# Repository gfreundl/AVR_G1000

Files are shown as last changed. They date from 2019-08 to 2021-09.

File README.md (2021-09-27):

G1000 HID unit 

This is a hardware simulator for the G1000, the most popular glass cockpit system in the GA fleet.  

The 3D model is based on the original device, has accurate dimensions and is available in STP format.  

Schematics and PCB layout are in the Eagle folder.  
All inputs are read by three ATMega16 MCU with USB firmware, linked together on a FE1.1s USB Hub chip.
No BOM is provided, as most parts are generic. The encoders are Alps STEC (volume) and ELMA E33 / E37 (all others)
The joystick is an Alps RKJXT1F42001, which is soldered on the copper side.

Sourcecode is mainly based on the V-USB driver firmware from obdev/v-usb

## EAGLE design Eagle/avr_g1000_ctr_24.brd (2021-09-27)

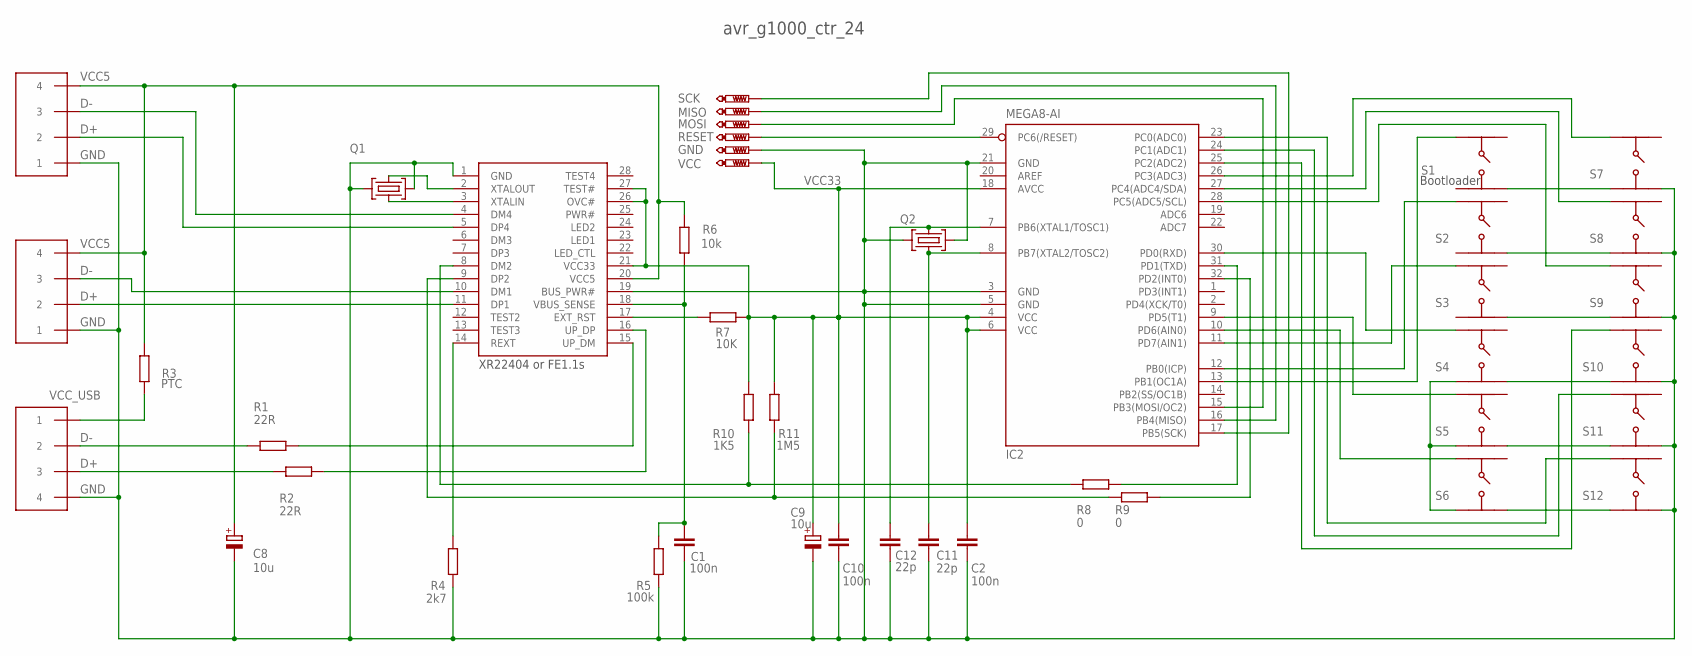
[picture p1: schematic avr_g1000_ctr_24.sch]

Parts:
C1, C2, C10: 100n; C0402
C8, C9: 10u; SMC_A
C11, C12: 22p; C0402
GND: PTR1TP10R; TP10R
IC2: MEGA8-AI; TQFP32-08
MISO: PTR1TP10R; TP10R
MOSI: PTR1TP10R; TP10R
Q1: 12MHz; OSCCC500X320X100
Q2: 12Mhz; OSCCC500X320X100
R1, R2: 22R; R0603
R3: PTC; R0805
R4: 2k7; R0603
R5: 100k; R0603
R6: 10k; R0603
R7: 10K; R0603
R8, R9: 0; R0603
R10: 1K5; R0603
R11: 1M5; R0603
RESET: PTR1TP10R; TP10R
S1, S2, S3, S4, S5, S6, S7, S8, S9, S10, S11, S12: B3FS1000
SCK: PTR1TP10R; TP10R
U$1, U$2, U$3: HEADER4X1.27
VCC: PTR1TP10R; TP10R
XR22404: XR22404

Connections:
D+: R2.1, U$1.P3 (3)
D-: R1.1, U$1.P2 (2)
DM1: U$2.P3 (3), XR22404.10 (DM1)
DM2: R8.1, R10.1, XR22404.8 (DM2)
DM4: U$3.P3 (3), XR22404.4 (DM4)
DP1: U$2.P2 (2), XR22404.11 (DP1)
DP2: R9.1, R11.1, XR22404.9 (DP2)
DP4: U$3.P2 (2), XR22404.5 (DP4)
EXT_RST: R7.1, XR22404.17 (EXT_RST)
GND: C1.2, C2.2, C8.-, C9.-, C10.2, C11.2, C12.2, GND.TP, IC2.3 (GND), IC2.5 (GND), IC2.21 (GND), Q1.2 (GND1), Q1.4 (GND2), Q2.2 (GND1), Q2.4 (GND2), R4.1, R5.1, S1.1, S2.1, S3.1, S4.1, S4.2, S5.1, S5.2, S6.1, S6.2, S7.1, S7.2, S8.1, S8.2, S9.1, S9.2, S10.1, S10.2, S11.1, S11.2, S12.1, S12.2, U$1.P4 (4), U$2.P1 (1), U$3.P1 (1), XR22404.1 (GND), XR22404.19 (BUS_PWR#)
MISO: IC2.16 (PB4(MISO)), MISO.TP
MOSI: IC2.15 (PB3(MOSI/OC2)), MOSI.TP
PB0: IC2.12 (PB0(ICP)), S2.4
PB1: IC2.13 (PB1(OC1A)), S1.4
PC0: IC2.23 (PC0(ADC0)), S12.4
PC1: IC2.24 (PC1(ADC1)), S11.4
PC2: IC2.25 (PC2(ADC2)), S10.4
PC3: IC2.26 (PC3(ADC3)), S7.4
PC4: IC2.27 (PC4(ADC4/SDA)), S8.4
PC5: IC2.28 (PC5(ADC5/SCL)), S9.4
PD0: IC2.30 (PD0(RXD)), S4.4
PD1: IC2.31 (PD1(TXD)), R8.2
PD2: IC2.32 (PD2(INT0)), R9.2
PD5: IC2.9 (PD5(T1)), S5.4
PD6: IC2.10 (PD6(AIN0)), S6.4
PD7: IC2.11 (PD7(AIN1)), S3.4
RESET: IC2.29 (PC6(/RESET)), RESET.TP
REXT: R4.2, XR22404.14 (REXT)
SCK: IC2.17 (PB5(SCK)), SCK.TP
UP_DM: R1.2, XR22404.15 (UP_DM)
UP_DP: R2.2, XR22404.16 (UP_DP)
VBUS_SENSE: C1.1, R5.2, R6.1, XR22404.18 (VBUS_SENSE)
VCC5: C8.+, R3.2, R6.2, U$2.P4 (4), U$3.P4 (4), XR22404.20 (VCC5)
VCC33: C2.1, C9.+, C10.1, IC2.4 (VCC), IC2.6 (VCC), IC2.18 (AVCC), R7.2, R10.2, R11.2, VCC.TP, XR22404.21 (VCC33), XR22404.26 (OVC#), XR22404.27 (TEST#)
VCC_USB: R3.1, U$1.P1 (1)
XTAL1: C12.1, IC2.7 (PB6(XTAL1/TOSC1)), Q2.1 (CRYSTAL1)
XTAL2: C11.1, IC2.8 (PB7(XTAL2/TOSC2)), Q2.3 (CRYSTAL2)
XTALIN: Q1.3 (CRYSTAL2), XR22404.3 (XTALIN)
XTALOUT: Q1.1 (CRYSTAL1), XR22404.2 (XTALOUT)

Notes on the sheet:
avr_g1000_ctr_24
XR22404 or FE1.1s
Bootloader

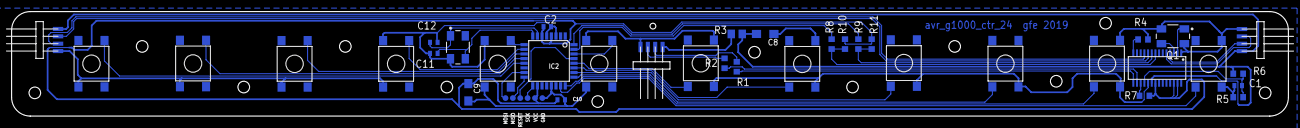
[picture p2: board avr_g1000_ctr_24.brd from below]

Board: 2 copper layers, 220.0 x 18.0 mm, 43 parts (43 on the bottom side), 39 nets.

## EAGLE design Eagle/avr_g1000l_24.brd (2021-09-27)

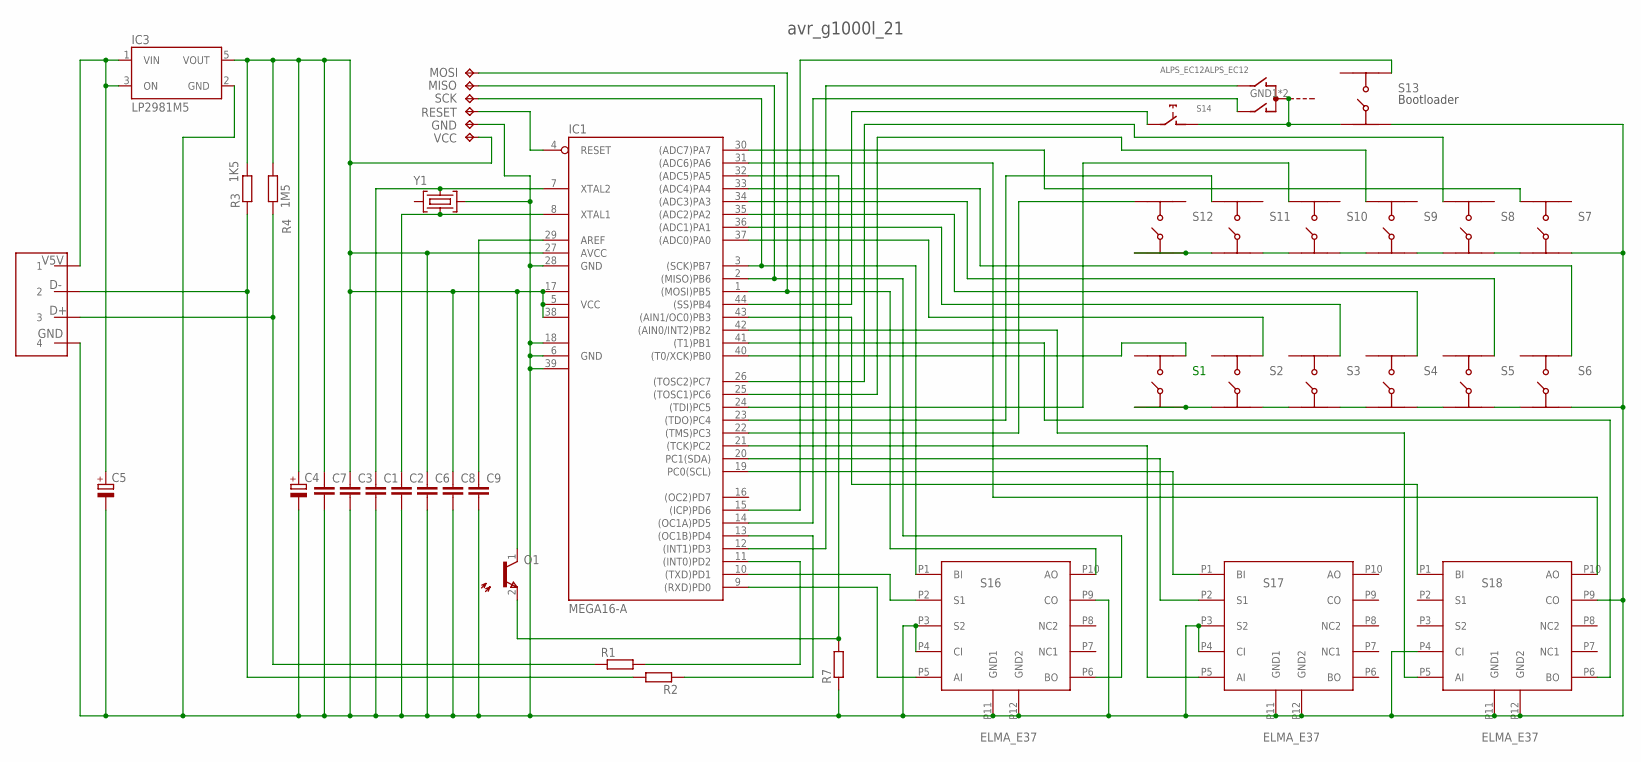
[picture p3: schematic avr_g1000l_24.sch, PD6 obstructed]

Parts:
C1, C2, C3, C6, C7, C8, C9: C-EUC0402; C0402
C4, C5: CPOL-EUSMCA; SMC_A
GND: TPTP10R; TP10R
IC1: MEGA16-A; TQFP44
IC3: LP2981M5; SOT23-5
MISO: TPTP10R; TP10R
MOSI: TPTP10R; TP10R
O1: KPS-3227KPS-3227; RESC3216X110
R1, R2, R7: R-EU_R0603; R0603
R3: 1K5; R0603
R4: 1M5; R0603
RESET: TPTP10R; TP10R
S1, S2, S3, S4, S5, S6, S7, S8, S9, S10, S11, S12, S13: B3FS1000
S14: ALPS_EC12ALPS_EC12; ALPS_EC12E_SW
S16, S17, S18: ELMA_E37
SCK: TPTP10R; TP10R
U$4: HEADER4X1.27
VCC: TPTP10R; TP10R
Y1: MJ-CRYSTALMJ; OSCCC500X320X100

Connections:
D+: R2.2, R3.1, U$4.P2 (2)
D-: R1.1, R4.1, U$4.P3 (3)
GND: C1.2, C2.2, C3.2, C4.-, C5.-, C6.2, C7.2, C8.2, C9.2, GND.TP, IC1.6 (GND), IC1.18 (GND1), IC1.28 (GND), IC1.39 (GND2), IC3.2 (GND), R7.1, S1.3, S1.4, S2.3, S2.4, S3.3, S3.4, S4.3, S4.4, S5.3, S5.4, S6.3, S6.4, S7.3, S7.4, S8.3, S8.4, S9.3, S9.4, S10.3, S10.4, S11.3, S11.4, S12.3, S12.4, S13.3, S13.4, S14.C, S14.D (1), S14.GND1 (G), S14.GND2 (G), S16.P3 (S2), S16.P4 (CI), S16.P9 (CO), S16.P11 (GND1), S16.P12 (GND2), S17.P3 (S2), S17.P4 (CI), S17.P11 (GND1), S17.P12 (GND2), S18.P4 (CI), S18.P9 (CO), S18.P11 (GND1), S18.P12 (GND2), U$4.P4 (4), Y1.2 (GND1)
PA0: IC1.37 ((ADC0)PA0), S2.2
PA1: IC1.36 ((ADC1)PA1), S3.2
PA2: IC1.35 ((ADC2)PA2), S4.2
PA3: IC1.34 ((ADC3)PA3), S5.2
PA4: IC1.33 ((ADC4)PA4), S6.2
PA5: IC1.32 ((ADC5)PA5), O1.2 (E), R7.2
PA6: IC1.31 ((ADC6)PA6), S18.P10 (AO)
PA7: IC1.30 ((ADC7)PA7), S7.1
PB0: IC1.40 ((T0/XCK)PB0), S1.2
PB1: IC1.41 ((T1)PB1), S18.P6 (BO)
PB2: IC1.42 ((AIN0/INT2)PB2), S18.P5 (AI)
PB3: IC1.43 ((AIN1/OC0)PB3), S18.P1 (BI)
PB4: IC1.44 ((SS)PB4), S14.E (2)
PB5: IC1.3 ((SCK)PB7), S16.P1 (BI), SCK.TP
PB6: IC1.1 ((MOSI)PB5), MOSI.TP, S16.P10 (AO)
PB7: IC1.2 ((MISO)PB6), MISO.TP, S16.P6 (BO)
PC0: IC1.19 (PC0(SCL)), S17.P1 (BI)
PC1: IC1.20 (PC1(SDA)), S17.P2 (S1)
PC2: IC1.21 ((TCK)PC2), S17.P5 (AI)
PC3: IC1.22 ((TMS)PC3), S12.1
PC4: IC1.23 ((TDO)PC4), S11.1
PC5: IC1.24 ((TDI)PC5), S10.1
PC6: IC1.25 ((TOSC1)PC6), S9.1
PC7: IC1.26 ((TOSC2)PC7), S8.1
PD0: IC1.9 ((RXD)PD0), S16.P5 (AI)
PD1: IC1.10 ((TXD)PD1), S16.P2 (S1)
PD2: IC1.13 ((OC1B)PD4), R2.1
PD3: IC1.12 ((INT1)PD3), S14.B
PD4: IC1.11 ((INT0)PD2), R1.2
PD5: IC1.14 ((OC1A)PD5), S14.A
PD6: IC1.15 ((ICP)PD6), S13.2
RESET: IC1.4 (RESET), RESET.TP
V5V: C5.+, IC3.1 (VIN), IC3.3 (ON), U$4.P1 (1)
VCC: C3.1, C4.+, C6.1, C7.1, C8.1, IC1.5 (VCC), IC1.17 (VCC1), IC1.27 (AVCC), IC1.38 (VCC2), IC3.5 (VOUT), O1.1 (C), R3.2, R4.2, VCC.TP
VREF: C9.1, IC1.29 (AREF)
XTAL1: C2.1, IC1.8 (XTAL1), Y1.3 (CRYSTAL2)
XTAL2: C1.1, IC1.7 (XTAL2), Y1.1 (CRYSTAL1)

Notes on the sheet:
avr_g1000l_21
Bootloader

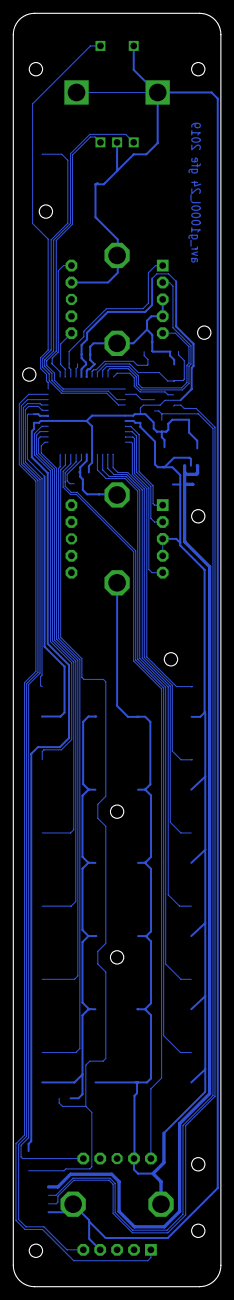
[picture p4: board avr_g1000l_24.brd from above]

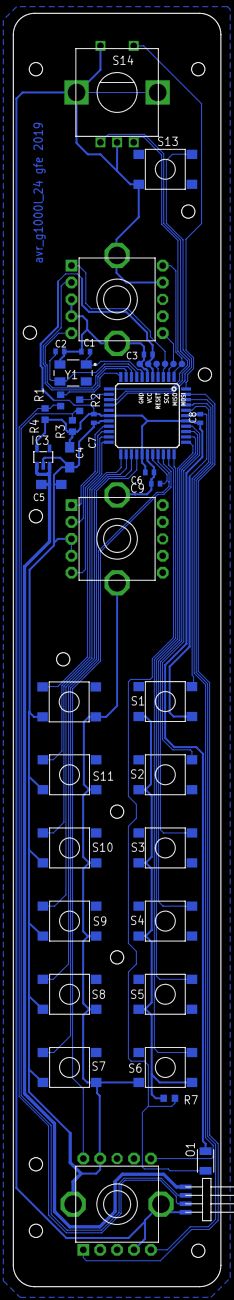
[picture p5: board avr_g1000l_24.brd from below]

Board: 2 copper layers, 31.2 x 191.4 mm, 42 parts (42 on the bottom side), 40 nets.

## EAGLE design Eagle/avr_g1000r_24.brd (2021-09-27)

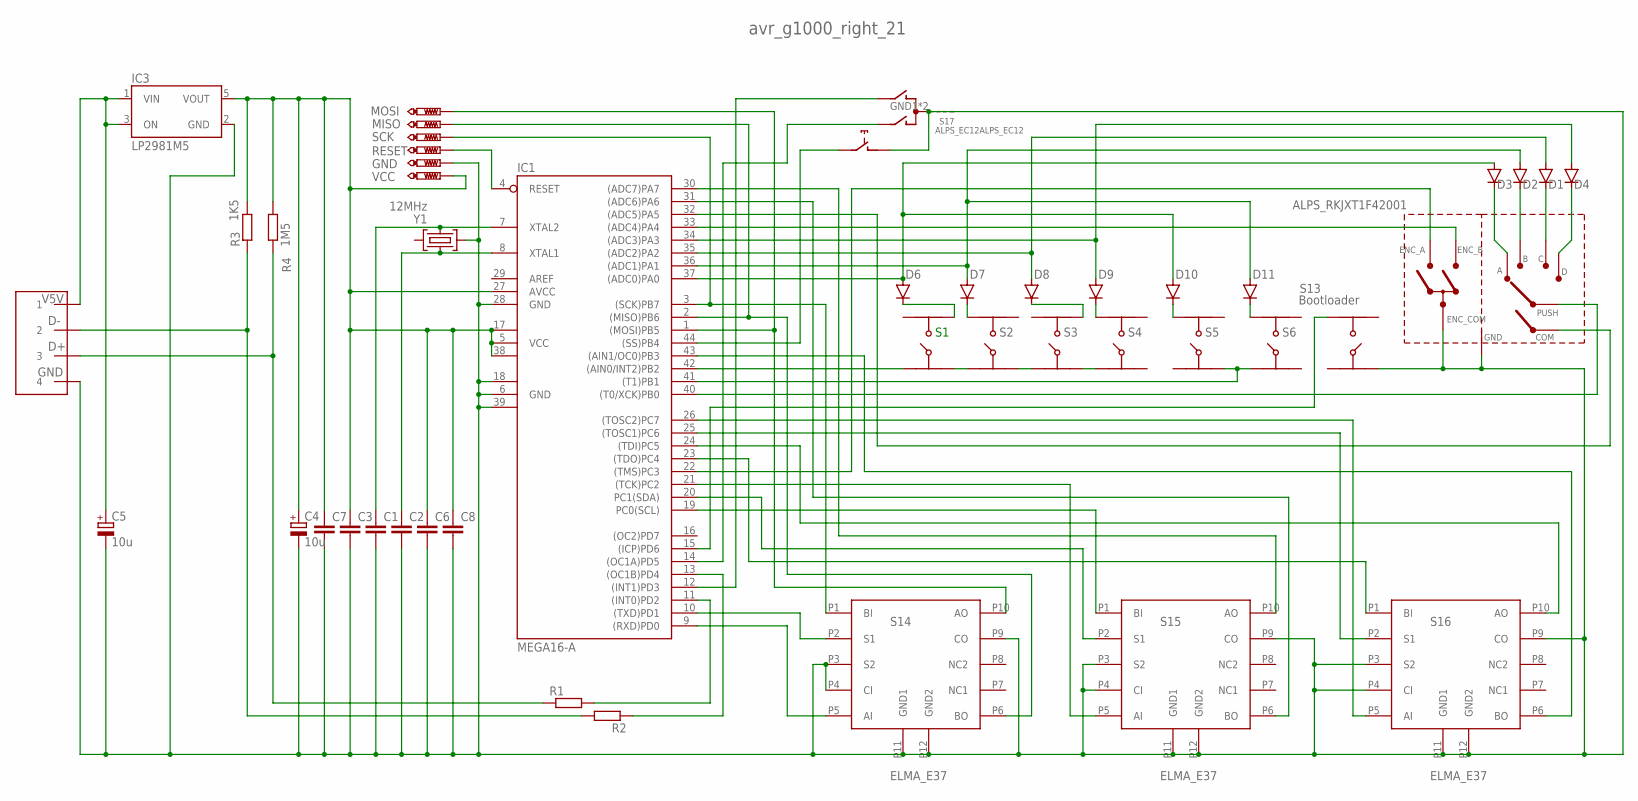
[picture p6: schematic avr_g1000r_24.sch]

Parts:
C1, C2, C3, C6, C7, C8: C-EUC0402; C0402
C4, C5: 10u; SMC_A
D1, D2, D3, D4, D6, D7, D8, D9, D10, D11: DIODE-SOD123; SOD123
GND: PTR1TP10R; TP10R
IC1: MEGA16-A; TQFP44
IC3: LP2981M5; SOT23-5
MISO: PTR1TP10R; TP10R
MOSI: PTR1TP10R; TP10R
R1, R2: R-EU_R0603; R0603
R3: 1K5; R0603
R4: 1M5; R0603
RESET: PTR1TP10R; TP10R
S1, S2, S3, S4, S5, S6: B3FS1000
S7: RKJXT1F42001
S13: Bootloader; B3FS1000
S14, S15, S16: ELMA_E37
S17: ALPS_EC12ALPS_EC12; ALPS_EC12E_SW
SCK: PTR1TP10R; TP10R
U$4: HEADER4X1.27
VCC: PTR1TP10R; TP10R
Y1: 12MHz; OSCCC500X320X100

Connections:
D1: D1.C, S7.C
D2: D2.C, S7.B
D3: D3.C, S7.A
D4: D4.C, S7.D
D7: D7.C, S2.1
D8: D8.C, S3.2
D10: D10.C, S5.1
D11: D11.C, S6.1
D+: R1.1, R4.1, U$4.P3 (3)
D-: R2.2, R3.1, U$4.P2 (2)
GND: C1.2, C2.2, C3.2, C4.-, C5.-, C6.2, C7.2, C8.2, GND.TP, IC1.6 (GND), IC1.18 (GND1), IC1.28 (GND), IC1.39 (GND2), IC3.2 (GND), S7.ENC_COM, S7.GND, S13.3, S14.P3 (S2), S14.P4 (CI), S14.P9 (CO), S14.P11 (GND1), S14.P12 (GND2), S15.P3 (S2), S15.P4 (CI), S15.P9 (CO), S15.P11 (GND1), S15.P12 (GND2), S16.P3 (S2), S16.P4 (CI), S16.P9 (CO), S16.P11 (GND1), S16.P12 (GND2), S17.C, S17.D (1), S17.GND1 (G), S17.GND2 (G), U$4.P4 (4), Y1.2 (GND1)
unnamed: D9.C, S4.1
unnamed: IC1.21 ((TCK)PC2), S15.P5 (AI)
unnamed: D6.C, S1.2
PA0: D3.A, D6.A, D10.A, IC1.37 ((ADC0)PA0)
PA1: D2.A, D7.A, D11.A, IC1.36 ((ADC1)PA1)
PA2: D1.A, D8.A, IC1.35 ((ADC2)PA2)
PA3: D4.A, D9.A, IC1.34 ((ADC3)PA3)
PA4: IC1.33 ((ADC4)PA4), S7.ENC_B
PA5: IC1.32 ((ADC5)PA5), S7.COM
PA6: IC1.31 ((ADC6)PA6), S15.P6 (BO)
PA7: IC1.30 ((ADC7)PA7), S15.P10 (AO)
PB0: IC1.40 ((T0/XCK)PB0), S7.PUSH
PB1: IC1.41 ((T1)PB1), S5.4, S6.3
PB2: IC1.42 ((AIN0/INT2)PB2), S1.3, S1.4, S2.3, S2.4, S3.3, S3.4, S4.3
PB3: IC1.43 ((AIN1/OC0)PB3), S16.P6 (BO)
PB4: IC1.44 ((SS)PB4), S17.E (2)
PB5: IC1.1 ((MOSI)PB5), MOSI.TP, S14.P10 (AO)
PB6: IC1.2 ((MISO)PB6), MISO.TP, S14.P6 (BO)
PB7: IC1.3 ((SCK)PB7), S14.P1 (BI), SCK.TP
PC0: IC1.19 (PC0(SCL)), S15.P1 (BI)
PC1: IC1.20 (PC1(SDA)), S15.P2 (S1)
PC3: IC1.22 ((TMS)PC3), S7.ENC_A
PC4: IC1.23 ((TDO)PC4), S16.P1 (BI)
PC5: IC1.24 ((TDI)PC5), S16.P10 (AO)
PC6: IC1.25 ((TOSC1)PC6), S16.P2 (S1)
PC7: IC1.26 ((TOSC2)PC7), S16.P5 (AI)
PD0: IC1.9 ((RXD)PD0), S14.P5 (AI)
PD1: IC1.10 ((TXD)PD1), S14.P2 (S1)
PD2: IC1.11 ((INT0)PD2), R1.2
PD3: IC1.12 ((INT1)PD3), S17.B
PD4: IC1.13 ((OC1B)PD4), R2.1
PD5: IC1.14 ((OC1A)PD5), S17.A
PD6: IC1.15 ((ICP)PD6), S13.2
RESET: IC1.4 (RESET), RESET.TP
V5V: C5.+, IC3.1 (VIN), IC3.3 (ON), U$4.P1 (1)
VCC: C3.1, C4.+, C6.1, C7.1, C8.1, IC1.5 (VCC), IC1.17 (VCC1), IC1.27 (AVCC), IC1.38 (VCC2), IC3.5 (VOUT), R3.2, R4.2, VCC.TP
XTAL1: C2.1, IC1.8 (XTAL1), Y1.3 (CRYSTAL2)
XTAL2: C1.1, IC1.7 (XTAL2), Y1.1 (CRYSTAL1)

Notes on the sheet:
ALPS_RKJXT1F42001
avr_g1000_right_21

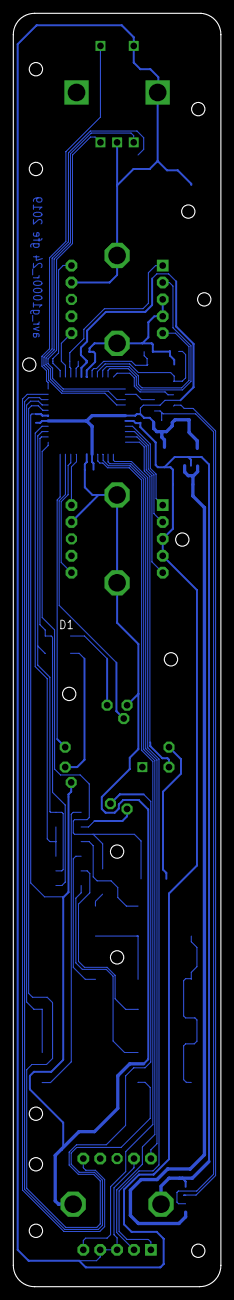
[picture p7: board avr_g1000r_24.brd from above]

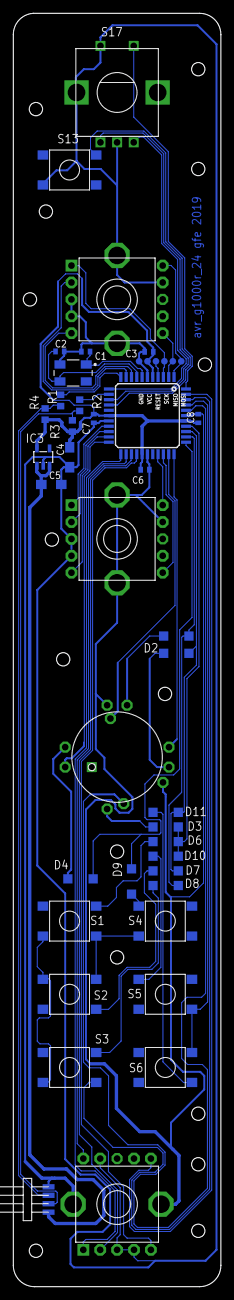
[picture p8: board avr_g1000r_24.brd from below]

Board: 2 copper layers, 31.2 x 191.4 mm, 44 parts (44 on the bottom side), 49 nets.

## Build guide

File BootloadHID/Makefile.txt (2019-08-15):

# Name: Makefile
# Project: bootloadHID
# Author: Christian Starkjohann
# Creation Date: 2007-03-19
# Tabsize: 4
# Copyright: (c) 2007 by OBJECTIVE DEVELOPMENT Software GmbH
# License: GNU GPL v2 (see License.txt)
# This Revision: $Id$

###############################################################################
# Configure the following variables according to your AVR. The example below
# is for an ATMega8. Program the device with
#     make fuse    # to set the clock generator, boot section size etc.
#     make flash   # to load the boot loader into flash
#     make lock    # to protect the boot loader from overwriting

DEVICE = atmega16a
BOOTLOADER_ADDRESS = 3800
F_CPU = 12000000
FUSEH = 0xd0
FUSEL = 0xff
# Fuse high byte:
# 0xc0 = 1 1 0 0   0 0 0 0 <-- BOOTRST (boot reset vector at 0x1800)
#        ^ ^ ^ ^   ^ ^ ^------ BOOTSZ0
#        | | | |   | +-------- BOOTSZ1
#        | | | |   + --------- EESAVE (preserve EEPROM over chip erase)
#        | | | +-------------- CKOPT (full output swing)
#        | | +---------------- SPIEN (allow serial programming)
#        | +------------------ WDTON (WDT not always on)
#        +-------------------- RSTDISBL (reset pin is enabled)
# Fuse low byte:
# 0x9f = 1 0 0 1   1 1 1 1
#        ^ ^ \ /   \--+--/
#        | |  |       +------- CKSEL 3..0 (external >8M crystal)
#        | |  +--------------- SUT 1..0 (crystal osc, BOD enabled)
#        | +------------------ BODEN (BrownOut Detector enabled)
#        +-------------------- BODLEVEL (2.7V)

###############################################################################

AVRDUDE = avrdude -c stk500v2 -P avrdoper -p $(DEVICE)

LDFLAGS += -Wl,--relax,--gc-sections -Wl,--section-start=.text=$(BOOTLOADER_ADDRESS)

# Omit -fno-* options when using gcc 3, it does not support them.
# COMPILE = avr-gcc -Wall -fno-move-loop-invariants -fno-tree-scev-cprop -fno-inline-small-functions -Iusbdrv -I. -mmcu=$(DEVICE) -DF_CPU=$(F_CPU) -DDEBUG_LEVEL=0 # -DTEST_MODE
# COMPILE = avr-gcc -Wall -Os -fno-move-loop-invariants -fno-tree-scev-cprop -fno-inline-small-functions -Iusbdrv -I. -mmcu=$(DEVICE) -DF_CPU=$(F_CPU) -DDEBUG_LEVEL=2 # -DTEST_MODE
COMPILE = avr-gcc -Wall -Os -fno-move-loop-invariants -fno-tree-scev-cprop -fno-inline-small-functions -Iusbdrv -I. -mmcu=$(DEVICE) -DF_CPU=$(F_CPU) -DDEBUG_LEVEL=0 # -DTEST_MODE
# NEVER compile the final product with debugging! Any debug output will
# distort timing so that the specs can't be met.

OBJECTS =  usbdrv/usbdrvasm.o usbdrv/oddebug.o main.o

# symbolic targets:
all:	main.hex

.c.o:
	$(COMPILE) -c $< -o $@

.S.o:
	$(COMPILE) -x assembler-with-cpp -c $< -o $@
# "-x assembler-with-cpp" should not be necessary since this is the default
# file type for the .S (with capital S) extension. However, upper case
# characters are not always preserved on Windows. To ensure WinAVR
# compatibility define the file type manually.

.c.s:
	$(COMPILE) -S $< -o $@

flash:	all
	$(AVRDUDE) -U flash:w:main.hex:i

readflash:
	$(AVRDUDE) -U flash:r:read.hex:i

fuse:
	$(AVRDUDE) -U hfuse:w:$(FUSEH):m -U lfuse:w:$(FUSEL):m

lock:
	$(AVRDUDE) -U lock:w:0x2f:m

read_fuses:
	$(UISP) --rd_fuses

clean:
	rm -f main.hex main.bin *.o usbdrv/*.o main.s usbdrv/oddebug.s usbdrv/usbdrv.s

# file targets:
main.bin:	$(OBJECTS)
	$(COMPILE) -o main.bin $(OBJECTS) $(LDFLAGS)

main.hex:	main.bin
	rm -f main.hex main.eep.hex
	avr-objcopy -j .text -j .data -O ihex main.bin main.hex
	avr-size main.hex

disasm:	main.bin
	avr-objdump -d main.bin

cpp:
	$(COMPILE) -E main.c

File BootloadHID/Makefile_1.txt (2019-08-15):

# Name: Makefile
# Project: bootloadHID
# Author: Christian Starkjohann
# Creation Date: 2007-03-19
# Tabsize: 4
# Copyright: (c) 2007 by OBJECTIVE DEVELOPMENT Software GmbH
# License: GNU GPL v2 (see License.txt)
# This Revision: $Id$

###############################################################################
# Configure the following variables according to your AVR. The example below
# is for an ATMegaxx. Program the device with
#     make fuse    # to set the clock generator, boot section size etc.
#     make flash   # to load the boot loader into flash
#     make lock    # to protect the boot loader from overwriting

DEVICE = atmega16a
BOOTLOADER_ADDRESS = 0x3800
F_CPU = 12000000
FUSEH = 0xd0
FUSEL = 0xff
#
# Fuse high byte:
# 0xc0 = 1 1 0 1   0 0 0 0 <-- BOOTRST (boot reset vector at 0x1c00)
#        ^ ^ ^ ^   ^ ^ ^------ BOOTSZ0
#        | | | |   | +-------- BOOTSZ1
#        | | | |   + --------- EESAVE (preserve EEPROM over chip erase)
#        | | | +-------------- CKOPT (unprogrammed)
#        | | +---------------- SPIEN (allow serial programming)
#        | +------------------ JTAGEN (disabled)
#        +-------------------- OCDEN (disabled)
# Fuse low byte:
# 0xe8 = 1 1 1 1   1 1 1 1
#        ^ ^ \ /   \--+--/
#        | |  |       +------- CKSEL 3..0 (external >8M crystal)
#        | |  +--------------- SUT 1..0 (slow rising power)
#        | +------------------ BODEN (BrownOut Detector disabled)
#        +-------------------- BODLEVEL (unprogrammed)
#
#----------------------------------------------------------------------------
#
# original version for atmega8
# Fuse high byte:
# 0xc0 = 1 1 0 0   0 0 0 0 <-- BOOTRST (boot reset vector at 0x1800)
#        ^ ^ ^ ^   ^ ^ ^------ BOOTSZ0
#        | | | |   | +-------- BOOTSZ1
#        | | | |   + --------- EESAVE (preserve EEPROM over chip erase)
#        | | | +-------------- CKOPT (full output swing)
#        | | +---------------- SPIEN (allow serial programming)
#        | +------------------ WDTON (WDT not always on)
#        +-------------------- RSTDISBL (reset pin is enabled)
# Fuse low byte:
# 0x9f = 1 0 0 1   1 1 1 1
#        ^ ^ \ /   \--+--/
#        | |  |       +------- CKSEL 3..0 (external >8M crystal)
#        | |  +--------------- SUT 1..0 (crystal osc, BOD enabled)
#        | +------------------ BODEN (BrownOut Detector enabled)
#        +-------------------- BODLEVEL (2.7V)

###############################################################################

AVRDUDE = avrdude -c stk500v2 -P avrdoper -p $(DEVICE)

LDFLAGS += -Wl,--relax,--gc-sections -Wl,--section-start=.text=$(BOOTLOADER_ADDRESS)

# Omit -fno-* options when using gcc 3, it does not support them.
COMPILE = avr-gcc -Wall -Os -fno-move-loop-invariants -fno-tree-scev-cprop -fno-inline-small-functions -Iusbdrv -I. -mmcu=$(DEVICE) -DF_CPU=$(F_CPU) -DDEBUG_LEVEL=0 # -DTEST_MODE
# NEVER compile the final product with debugging! Any debug output will
# distort timing so that the specs can't be met.

OBJECTS =  usbdrv/usbdrvasm.o usbdrv/oddebug.o main.o

# symbolic targets:
all:	main.hex

.c.o:
	$(COMPILE) -c $< -o $@

.S.o:
	$(COMPILE) -x assembler-with-cpp -c $< -o $@
# "-x assembler-with-cpp" should not be necessary since this is the default
# file type for the .S (with capital S) extension. However, upper case
# characters are not always preserved on Windows. To ensure WinAVR
# compatibility define the file type manually.

.c.s:
	$(COMPILE) -S $< -o $@

flash:	all
	$(AVRDUDE) -U flash:w:main.hex:i

readflash:
	$(AVRDUDE) -U flash:r:read.hex:i

fuse:
	$(AVRDUDE) -U hfuse:w:$(FUSEH):m -U lfuse:w:$(FUSEL):m

lock:
	$(AVRDUDE) -U lock:w:0x2f:m

read_fuses:
	$(UISP) --rd_fuses

clean:
	rm -f main.hex main.bin *.o usbdrv/*.o main.s usbdrv/oddebug.s usbdrv/usbdrv.s

# file targets:
main.bin:	$(OBJECTS)
	$(COMPILE) -o main.bin $(OBJECTS) $(LDFLAGS)

main.hex:	main.bin
	rm -f main.hex main.eep.hex
	avr-objcopy -j .text -j .data -O ihex main.bin main.hex
	avr-size main.hex

disasm:	main.bin
	avr-objdump -d main.bin

cpp:
	$(COMPILE) -E main.c

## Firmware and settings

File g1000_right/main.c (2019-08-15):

/* Name: main.c
 * Project: hid-mouse, a very simple HID example
 * Author: Christian Starkjohann
 * Creation Date: 2008-04-07
 * Tabsize: 4
 * Copyright: (c) 2008 by OBJECTIVE DEVELOPMENT Software GmbH
 * License: GNU GPL v2 (see License.txt), GNU GPL v3 or proprietary (CommercialLicense.txt)
 */

/*
This example should run on most AVRs with only little changes. No special
hardware resources except INT0 are used. You may have to change usbconfig.h for
different I/O pins for USB. Please note that USB D+ must be the INT0 pin, or
at least be connected to INT0 as well.

We use VID/PID 0x046D/0xC00E which is taken from a Logitech mouse. Don't
publish any hardware using these IDs! This is for demonstration only!
*/



/*

gfe

	310119: 
	matrix works ok so far, tested with 2x2 button matrix and diodes
	DBG output commented, invokes 1ms delay per line
	every 19 full sequences (18ms) pause in read for 13ms, presumably USB send
	delays with _delay_ms funktion work ok, _delay_us only to certain maximum
	
	ReadButtons function seems superfluent
	
	DBG Debug IDs for V-USB:
	02	polling
	03	about to send
	10	Rx data from usbProcessRx
	20	Tx data from usbBuildTxBlock
	21	interrupt data from usbGenericSetInterrupt
	ff	reset
	1d	Setup from usbProcessRx

	9x	my debug IDs
	//

	240219
	all encoders tested and crosschecked with schematic avr_g1000r_04.sch
	timings checked in simulator and breadboard

	OIL:
	switches to be checked, especially D1 (TXEN)
*/

#define F_CPU	12000000UL
#include <avr/io.h>
#include <avr/wdt.h>
#include <avr/interrupt.h>  /* for sei() */
#include <util/delay.h>     /* for _delay_ms() */

#include <avr/pgmspace.h>   /* required by usbdrv.h */
#include "usbdrv.h"
#include "oddebug.h"        /* This is also an example for using debug macros */

/* ----------------------------- USB interface ----------------------------- */
PROGMEM const char usbHidReportDescriptor[23] = { /* USB report descriptor, size must match usbconfig.h */
    0x05, 0x01,                    // USAGE_PAGE (Generic Desktop)
    0x09, 0x05,                    // USAGE (Joystick)
    0xA1, 0x01,                    // COLLECTION (Application)
    0x05, 0x09,                    //     USAGE (Button)
    0x19, 0x01,                    //     USAGE_MINIMUM
    0x29, 0x20,                    //     USAGE_MAXIMUM
    0x15, 0x00,                    //     LOGICAL_MINIMUM (0)
    0x25, 0x01,                    //     LOGICAL_MAXIMUM (1)
    0x75, 0x01,                    //     REPORT_SIZE (1)
    0x95, 0x20,                    //     REPORT_COUNT (32)
    0x81, 0x02,                    //     INPUT (Data,Var,Abs)
    0xC0                          // END COLLECTION
};

typedef struct{
    uchar	a1;
    uchar   a2;
    uchar   a3;
    uchar   a4;
}report_t;
static report_t reportBuffer;
static uchar    idleRate;		/* repeat rate for keyboards, never used for mice */

uchar btn[32];					//buttons
int n = 0;
int c = 1;
uchar buttons[4];
uchar enc[8];					//encoders
uchar Dets;						//Counter for encoder detents per timer cycle
uchar pot[8];					//analog inputs

void ReadEncoder(void);
void init_TC1(void);
void ReadButton(void);
void ButtonMatrix();
void ReadAnalog(void);

/* ------------------------------------------------------------------------- */

usbMsgLen_t usbFunctionSetup(uchar data[8])
{
usbRequest_t    *rq = (void *)data;
    /* The following requests are never used. But since they are required by
     * the specification, we implement them in this example.    */
    if ((rq->bmRequestType & USBRQ_TYPE_MASK) == USBRQ_TYPE_CLASS)
	{    /* class request type */
        DBG1(0x50, &rq->bRequest, 1);   /* debug output: print our request */
        if (rq->bRequest == USBRQ_HID_GET_REPORT)
		{  /* wValue: ReportType (highbyte), ReportID (lowbyte) */
            /* we only have one report type, so don't look at wValue */
            usbMsgPtr = (void *)&reportBuffer;
            return sizeof(reportBuffer);
        }
		else if (rq->bRequest == USBRQ_HID_GET_IDLE)
		{
            usbMsgPtr = &idleRate;
            return 1;
        }
		else if (rq->bRequest == USBRQ_HID_SET_IDLE)
		{
            idleRate = rq->wValue.bytes[1];
        }
    }
	else
	{
        /* no vendor specific requests implemented */
    }
    return 0;   /* default for not implemented requests: return no data back to host */
}
/* ------------------------------------------------------------------------- */

int __attribute__((noreturn)) main(void)
{

	uchar   i;
	enc[0] = 0;					//encoders
	enc[1] = 0;
	enc[2] = 0;
	enc[3] = 0;
	enc[4] = 0;
	enc[5] = 0;
	enc[6] = 0;

	init_TC1();

    wdt_enable(WDTO_1S);
    /* Even if you don't use the watchdog, turn it off here. On newer devices,
     * the status of the watchdog (on/off, period) is PRESERVED OVER RESET!
     */
    odDebugInit();
    DBG1(0x00, 0, 0);       /* debug output: main starts */

    usbInit();
    usbDeviceDisconnect();  /* enforce re-enumeration, do this while interrupts are disabled! */
    i = 0;
    while(--i)				/* fake USB disconnect for > 250 ms */
	{             
        wdt_reset();
        _delay_ms(1);
    }
    usbDeviceConnect();
    sei();

    DBG1(0x01, 0, 0);       /* debug output: main loop starts */
    for(;;)					//main event loop
	{                

		ButtonMatrix();		//0.61ms

		//Process buttons
		//customize n for number of buttons												// <----- change here
		n = 0;
		while (n < 0)
		{
			ReadButton();
			n++;
		}

		DDRA &= 0b00000000;								//all ports input
		DDRB &= 0b00000000;								//ButtonMatrix ports handle DDR on their own
		DDRC &= 0b00000000;
		DDRD &= 0b00000000;								//USB ports handle DDR on their own
		PORTA |= 0b11111111;							//pull-up resistors
		PORTB |= 0b11111111;
		PORTC |= 0b11111111;
		PORTD |= 0b11101011;							//no pull-ups on USB ports PD2, PD4

		enc[0] = (enc[0] & 0b00001100) 
					| ((PINA & (1<<PINA4))>>3)			//Alps Encoder RKJX
					| ((PINC & (1<<PINC3))>>3);	
		enc[1] = (enc[1] & 0b00001100)
					| ((PIND & (1<<PIND3))>>2)			//Alps Encoder STEC SW1
					| ((PIND & (1<<PIND5))>>5);
		enc[2] = (enc[2] & 0b00001100) 
					| ((PINB & (1<<PINB7))>>6)			//ELMA Encoder U$1 inner
					| (PIND & (1<<PIND0));
		enc[3] = (enc[3] & 0b00001100)
					| ((PINB & (1<<PINB5))>>4)			//ELMA Encoder U$1 outer
					| ((PINB & (1<<PINB6))>>6);
		enc[4] = (enc[4] & 0b00001100)
					| ((PINC & (1<<PINC2))>>1)			//ELMA Encoder U$2 inner
					| (PINC & (1<<PINC0));
		enc[5] = (enc[5] & 0b00001100)
					| ((PINA & (1<<PINA7))>>6)			//ELMA Encoder U$2 outer
					| ((PINA & (1<<PINA6))>>6);
		enc[6] = (enc[6] & 0b00001100)
					| ((PINC & (1<<PINC7))>>6)			//ELMA Encoder U$3 inner
					| ((PINC & (1<<PINC4))>>4);
		enc[7] = (enc[7] & 0b00001100)
					| ((PINC & (1<<PINC5))>>4)			//ELMA Encoder U$3 outer
					| ((PINB & (1<<PINB3))>>3);
		n=0;
		while (n < 8)
		{
			ReadEncoder();
			n++;
		}

		//Process Analog Inputs
		//customize i for number of potentiometers									// <----- change here
		n = 0;											//ADC5 = PA5
		while (n < 0)
		{
			ReadAnalog();
			n++;
		}

		//Buttons displayed inverted in Windows GUI: LSB left, MSB right
		reportBuffer.a1 = (buttons[0] & 0b00001111)						//S1-4
							| ((buttons[1] & 0b00000011) <<4)			//S5-6
							| ((1<<PINB4) & ~(PINB & (1<<PINB4))) <<2	//SW1
							//| (((PINA & (1<<PINA5))<<2) ^ 0x80);		//RJKX Com
							| ((buttons[0] & 0b00100000)<<2);			//PINA5 = RJKX Com 
		reportBuffer.a2 = (buttons[2] & 0b00001111)						//RJKX A-D
							| ((1<<PIND6) & ~(PIND & (1<<PIND6))) <<1	//S13
							| ((1<<PIND1) & ~(PIND & (1<<PIND1))) <<5	//U1
							| ((1<<PINC1) & ~(PINC & (1<<PINC1))) <<4	//U2
							| ((1<<PINC6) & ~(PINC & (1<<PINC6))) >>2;	//U1
		//report encoders only when input change, to control pulse length
		if (c == 1)
		{
			reportBuffer.a3 = (enc[0] & 0b11000000) >>6
								| (enc[1] & 0b11000000) >>4
								| (enc[2] & 0b11000000) >>2
								| (enc[3] & 0b11000000);								;
			reportBuffer.a4 = (enc[4] & 0b11000000) >>6
								| (enc[5] & 0b11000000) >>4
								| (enc[6] & 0b11000000) >>2
								| (enc[7] & 0b11000000);
			c = 0;
			TIFR |= (1<<OCF1A);					//clear timer compare flag
			TCNT1 = 0x0000;						//restart timer
		}

		_delay_ms(1);							//for debouncing

		//control pulse length for encoders
		//check for time elapsed, if so, clear buffers carrying encoder
		if (TIFR & (1<<OCF1A))						
		{
			reportBuffer.a3 = 0; 				//clear encoders, don't clear buttons
			reportBuffer.a4 = 0;
			Dets = 0;
			TIFR |= (1<<OCF1A);					//clear timer compare flag
		}
			 
	    DBG1(0x02, 0, 0);   /* debug output: main loop iterates */
        wdt_reset();
        usbPoll();
        if(usbInterruptIsReady())
		{
 			DBG1(0x03, 0, 0);   /* debug output: interrupt report prepared */
			/* called after every poll of the interrupt endpoint */
			usbSetInterrupt((void *)&reportBuffer, sizeof(reportBuffer));
		}
    }
}

/* ------------------------------------------------------------------------- */

//compare new port bits with previous readout
//save port status in bits 2,3 for next comparison in next cycle
void ReadButton(void)
{
	char oldbtn;
	char newbtn;
	oldbtn = ((btn[n] & 0b00001100) >> 2);			//shift bits from last readout for compare
	newbtn = btn[n] & 0b00000011;					//only regard bits 0,1
	if ((newbtn ^ oldbtn) != 0)						//someting changed with this button ?
	{
		c = 1;
		oldbtn = (newbtn << 2);						//renew oldrty with newrty
		btn[n] = btn[n] & 0b11110011;				//clear oldrty bits within rty[i]
		btn[n] = (btn[n] | oldbtn);					//save "new" oldrty within rty[i]
	}//end if ((newbtn ^ oldbtn) != 0)
}//end ReadButton(void)

//general key matrix
//PB0-2 column output
//PA0-3 row input, PA5 special pin 'Com' on RKJX switch
void ButtonMatrix()
{
	uchar i = 0;
	DDRB &= 0b11111000;					//set columns input HiZ
	PORTB &= 0b11111000;				//prepare columns for output low
	DDRA &= 0b11110000;					//set rows input
	PORTA |= 0b00001111;				//set rows pull-ups on

	for (i=0;i<3;i++)
	{
		DDRB &= 0b11111000;				//(re-)set columns input HiZ
		DDRB |= 1<<i;		 			//set col k output, already set low
		_delay_ms(0.2);					//wait to settle & debounce
		buttons[i] = ~PINA;				//read, negate and save row
	}									//next col
}

//compare new port bits with previous readout
//determine direction of rotation and write into bits 7,6 (10=CW, 01=CCW)
//if number of repeated pulses of same direction (detents) > 4 => report fast rotation in bits 4,5
//save port status in bits 2,3 for next comparison in succeeding cycle
void ReadEncoder()
{
	char oldenc;
	char newenc;
	oldenc = ((enc[n] & 0b00001100) >> 2);			//align bits from last readout for compare
	newenc = (enc[n] & 0b00000011);					//only regard bits 0,1
	DBG1(0x93, newenc, 1);
	DBG1(0x94, oldenc, 1);
	if ((newenc ^ oldenc) != 0)						//something changed ?
	{
		DBG1(0x95, newenc, 1);
		c = 1;
		oldenc = oldenc << 1;						//shift left 1 bit
		oldenc = oldenc & 0b00000011;				//use only bits 0 and 1
		if ((newenc ^ oldenc) > 1)					//CCW rotation
		{
			if (Dets < 3)							//special treatment for 4 or more pulses within timer delay
			{
				enc[n] = (enc[n] | 0b01000000);
				Dets++;
			}
			else
			{
				enc[n] = (enc[n] | 0b00010000);
				Dets = 0;
			}
		}
		else										//CW rotation
		{
			if (Dets < 3)
			{
				enc[n] = (enc[n] | 0b10000000);
				Dets++;
			}
			else
			{
				enc[n] = (enc[n] | 0b00100000);
				Dets = 0;
			}
		}//end if ((read ^ oldenc[i]) > 1)
		oldenc = newenc << 2;						//renew oldenc with newenc
		enc[n] = enc[n] & 0b11110011;				//clear oldenc bits 2,3 within enc[i]
		enc[n] = (enc[n] | oldenc);					//save "new" oldenc within enc[i]
	}//end if (newenc ^ oldenc) != 0
}//end ReadEncoder()


//read analog inputs
//different handling of 8bit and 10bit ADC
void ReadAnalog(void)
{
	ADMUX = 0x60 | (n & 0x0f);						//AVCC, left justified
	ADCSRA = 0b11000111;							//Enable ADC, start conversion, prescaler 128
	while (ADCSRA & (1<<ADSC));						//wait until ADSC bit is reset by CPU after conversion is complete
	if (n < 6)										//8bit conversion
	{												//conversion including init takes 25 cycles instead of 13 cycles
		pot[n] = (ADCH);	
	}
	else											//10bit conversion
	{
		pot[n+8] = ADCL;							//requires 2 byte in report
		//pot[i+8] = (pot[i+8] ^ 0b10000000);		//value is signed, invert sign
		pot[n] = ADCH;								//read low byte first
	}
}

void init_TC1(void)
{
	//TCCR1A = (1<<COM1A1) ;				//clear OC1A pin on match
	TCCR1B |= (1 << WGM12);					//normal mode
	TCCR1B |= (1 << CS10)|(1 << CS12);		//1024 prescaler
	OCR1A = 0x300;							//65ms@12MHz, interval time = (1/clk)*prescaler*OCR1A
	//TIMSK1 |= (1 << OCIE1A);				//enable interrupt
}

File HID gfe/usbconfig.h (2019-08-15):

/* Name: usbconfig.h
 * Project: V-USB, virtual USB port for Atmel's(r) AVR(r) microcontrollers
 * Author: Christian Starkjohann
 * Creation Date: 2005-04-01
 * Tabsize: 4
 * Copyright: (c) 2005 by OBJECTIVE DEVELOPMENT Software GmbH
 * License: GNU GPL v2 (see License.txt), GNU GPL v3 or proprietary (CommercialLicense.txt)
 */

#ifndef __usbconfig_h_included__
#define __usbconfig_h_included__

/*
General Description:
This file is an example configuration (with inline documentation) for the USB
driver. It configures V-USB for USB D+ connected to Port D bit 2 (which is
also hardware interrupt 0 on many devices) and USB D- to Port D bit 4. You may
wire the lines to any other port, as long as D+ is also wired to INT0 (or any
other hardware interrupt, as long as it is the highest level interrupt, see
section at the end of this file).
*/

/* ---------------------------- Hardware Config ---------------------------- */

#define USB_CFG_IOPORTNAME      D
/* This is the port where the USB bus is connected. When you configure it to
 * "B", the registers PORTB, PINB and DDRB will be used.
 */
#define USB_CFG_DMINUS_BIT      4
/* This is the bit number in USB_CFG_IOPORT where the USB D- line is connected.
 * This may be any bit in the port.
 */
#define USB_CFG_DPLUS_BIT       2
/* This is the bit number in USB_CFG_IOPORT where the USB D+ line is connected.
 * This may be any bit in the port. Please note that D+ must also be connected
 * to interrupt pin INT0! [You can also use other interrupts, see section
 * "Optional MCU Description" below, or you can connect D- to the interrupt, as
 * it is required if you use the USB_COUNT_SOF feature. If you use D- for the
 * interrupt, the USB interrupt will also be triggered at Start-Of-Frame
 * markers every millisecond.]
 */
#define USB_CFG_CLOCK_KHZ       12000
/* Clock rate of the AVR in kHz. Legal values are 12000, 12800, 15000, 16000,
 * 16500, 18000 and 20000. The 12.8 MHz and 16.5 MHz versions of the code
 * require no crystal, they tolerate +/- 1% deviation from the nominal
 * frequency. All other rates require a precision of 2000 ppm and thus a
 * crystal!
 * Since F_CPU should be defined to your actual clock rate anyway, you should
 * not need to modify this setting.
 */
#define USB_CFG_CHECK_CRC       0
/* Define this to 1 if you want that the driver checks integrity of incoming
 * data packets (CRC checks). CRC checks cost quite a bit of code size and are
 * currently only available for 18 MHz crystal clock. You must choose
 * USB_CFG_CLOCK_KHZ = 18000 if you enable this option.
 */

/* ----------------------- Optional Hardware Config ------------------------ */

/* #define USB_CFG_PULLUP_IOPORTNAME   D */
/* If you connect the 1.5k pullup resistor from D- to a port pin instead of
 * V+, you can connect and disconnect the device from firmware by calling
 * the macros usbDeviceConnect() and usbDeviceDisconnect() (see usbdrv.h).
 * This constant defines the port on which the pullup resistor is connected.
 */
/* #define USB_CFG_PULLUP_BIT          4 */
/* This constant defines the bit number in USB_CFG_PULLUP_IOPORT (defined
 * above) where the 1.5k pullup resistor is connected. See description
 * above for details.
 */

/* --------------------------- Functional Range ---------------------------- */
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

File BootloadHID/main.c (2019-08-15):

/* Name: main.c
 * Project: AVR bootloader HID
 * Author: Christian Starkjohann
 * Creation Date: 2007-03-19
 * Tabsize: 4
 * Copyright: (c) 2007 by OBJECTIVE DEVELOPMENT Software GmbH
 * License: GNU GPL v2 (see License.txt)
 * This Revision: $Id$
 */

/*
* gfe Notes:
* see Notizen.txt
* bootloader condition needs to be met for whole flash operation!
* DBG is nop when DEBUG_LEVEL=0, not necessary to comment out
* BOOTRST Fuse is required, BOOT Sector lock optional
TEST_MODE used to verify report descriptor
*/


#include <avr/io.h>
#include <avr/interrupt.h>
#include <avr/pgmspace.h>
#include <avr/wdt.h>
#include <avr/boot.h>
#include <string.h>
#include <util/delay.h>

static void leaveBootloader() __attribute__((__noreturn__));

#include "bootloaderconfig.h"
#include "usbdrv.c"

/* ------------------------------------------------------------------------ */

#ifndef ulong
#   define ulong    unsigned long
#endif
#ifndef uint
#   define uint     unsigned int
#endif

#if (FLASHEND) > 0xffff /* we need long addressing */
#   define addr_t           ulong
#else
#   define addr_t           uint
#endif

static addr_t           currentAddress; /* in bytes */
static uchar            offset;         /* data already processed in current transfer */
#if BOOTLOADER_CAN_EXIT
static uchar            exitMainloop;
#endif


const PROGMEM char usbHidReportDescriptor[33] = {
    0x06, 0x00, 0xff,              // USAGE_PAGE (Generic Desktop)
    0x09, 0x01,                    // USAGE (Vendor Usage 1)
    0xa1, 0x01,                    // COLLECTION (Application)
    0x15, 0x00,                    //   LOGICAL_MINIMUM (0)
    0x26, 0xff, 0x00,              //   LOGICAL_MAXIMUM (255)
    0x75, 0x08,                    //   REPORT_SIZE (8)

    0x85, 0x01,                    //   REPORT_ID (1)
    0x95, 0x06,                    //   REPORT_COUNT (6)
    0x09, 0x00,                    //   USAGE (Undefined)
    0xb2, 0x02, 0x01,              //   FEATURE (Data,Var,Abs,Buf)

    0x85, 0x02,                    //   REPORT_ID (2)
    0x95, 0x83,                    //   REPORT_COUNT (131)
    0x09, 0x00,                    //   USAGE (Undefined)
    0xb2, 0x02, 0x01,              //   FEATURE (Data,Var,Abs,Buf)
    0xc0                           // END_COLLECTION
};

/* allow compatibility with avrusbboot's bootloaderconfig.h: */
#ifdef BOOTLOADER_INIT
#   define bootLoaderInit()         BOOTLOADER_INIT
#endif
#ifdef BOOTLOADER_CONDITION
#   define bootLoaderCondition()    BOOTLOADER_CONDITION
#endif

/* compatibility with ATMega88 and other new devices: */
#ifndef TCCR0
#define TCCR0   TCCR0B
#endif
#ifndef GICR
#define GICR    MCUCR
#endif

static void (*nullVector)(void) __attribute__((__noreturn__));

static void leaveBootloader()
{
    DBG1(0x01, 0, 0);
    cli();
    boot_rww_enable();
    USB_INTR_ENABLE = 0;
    USB_INTR_CFG = 0;       /* also reset config bits */
#if F_CPU == 12800000
    TCCR0 = 0;              /* default value */
#endif
    GICR = (1 << IVCE);     /* enable change of interrupt vectors */
    GICR = (0 << IVSEL);    /* move interrupts to application flash section */

/* We must go through a global function pointer variable instead of writing
 *  ((void (*)(void))0)();
 * because the compiler optimizes a constant 0 to "rcall 0" which is not
 * handled correctly by the assembler.
 */
//gfe: this dummy function makes program start from address 0x0000
    nullVector();				
}

uchar   usbFunctionSetup(uchar data[8])
{
usbRequest_t    *rq = (void *)data;
static uchar    replyBuffer[7] = {
        1,                              /* report ID */
        SPM_PAGESIZE & 0xff,
        SPM_PAGESIZE >> 8,
        ((long)FLASHEND + 1) & 0xff,
        (((long)FLASHEND + 1) >> 8) & 0xff,
        (((long)FLASHEND + 1) >> 16) & 0xff,
        (((long)FLASHEND + 1) >> 24) & 0xff
    };

    if(rq->bRequest == USBRQ_HID_SET_REPORT){
        if(rq->wValue.bytes[0] == 2){
            offset = 0;
            return USB_NO_MSG;
        }
#if BOOTLOADER_CAN_EXIT
        else{
            exitMainloop = 1;
        }
#endif
    }else if(rq->bRequest == USBRQ_HID_GET_REPORT){
        usbMsgPtr = (usbMsgPtr_t)replyBuffer;
        return 7;
    }
    return 0;
}

uchar usbFunctionWrite(uchar *data, uchar len)
{
union {
    addr_t  l;
    uint    s[sizeof(addr_t)/2];
    uchar   c[sizeof(addr_t)];
}       address;
uchar   isLast;

    address.l = currentAddress;
    if(offset == 0){
        DBG1(0x30, data, 3);
        address.c[0] = data[1];
        address.c[1] = data[2];
#if (FLASHEND) > 0xffff /* we need long addressing */
        address.c[2] = data[3];
        address.c[3] = 0;
#endif
        data += 4;
        len -= 4;
    }
    DBG1(0x31, (void *)&currentAddress, 4);
    offset += len;
    isLast = offset & 0x80; /* != 0 if last block received */
    do{
        addr_t prevAddr;
#if SPM_PAGESIZE > 256
        uint pageAddr;
#else
        uchar pageAddr;
#endif
        DBG1(0x32, 0, 0);
        pageAddr = address.s[0] & (SPM_PAGESIZE - 1);
        if(pageAddr == 0){              /* if page start: erase */
            DBG1(0x33, 0, 0);
#ifndef TEST_MODE
            cli();
            boot_page_erase(address.l); /* erase page */
            sei();
            boot_spm_busy_wait();       /* wait until page is erased */
#endif
        }
        cli();
        boot_page_fill(address.l, *(short *)data);
        sei();
        prevAddr = address.l;
        address.l += 2;
        data += 2;
        /* write page when we cross page boundary */
        pageAddr = address.s[0] & (SPM_PAGESIZE - 1);
        if(pageAddr == 0){
            DBG1(0x34, 0, 0);
#ifndef TEST_MODE
            cli();
            boot_page_write(prevAddr);
            sei();
            boot_spm_busy_wait();
#endif
        }
        len -= 2;
    }while(len);
    currentAddress = address.l;
    DBG1(0x35, (void *)&currentAddress, 4);
    return isLast;
}

static void initForUsbConnectivity(void)
{
uchar   i = 0;

#if F_CPU == 12800000
    TCCR0 = 3;          /* 1/64 prescaler */
#endif
    usbInit();
    /* enforce USB re-enumerate: */
    usbDeviceDisconnect();  /* do this while interrupts are disabled */
    do{             /* fake USB disconnect for > 250 ms */
        wdt_reset();
        _delay_ms(1);
    }while(--i);
    usbDeviceConnect();
    sei();
}
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
